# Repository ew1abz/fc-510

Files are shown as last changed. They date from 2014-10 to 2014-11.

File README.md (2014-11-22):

fc-510
======

Frequency Counter FC-510 by wubblick@yahoo.com

[http://radiokot.ru/forum/viewtopic.php?f=10&t=65025](http://radiokot.ru/forum/viewtopic.php?f=10&t=65025)

[www.youtube.com/watch?v=VNKCnef-ynU](www.youtube.com/watch?v=VNKCnef-ynU)

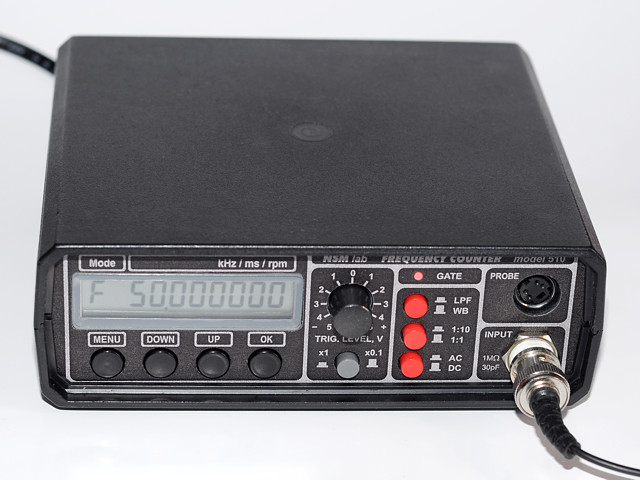
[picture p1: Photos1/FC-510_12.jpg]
requency Counter FC-510 by wubblick@yahoo.com


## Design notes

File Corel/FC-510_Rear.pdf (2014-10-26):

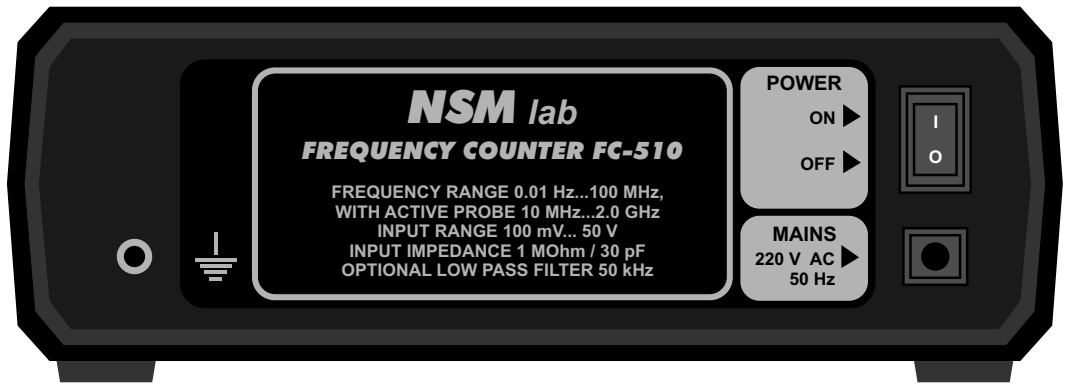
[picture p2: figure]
UEN; TER; NSM; OFF; POWER; MAINS; FREQUENCY RANGE 0.01 Hz...100 MHz, WITH ACTIVE PROBE 10 MHz...2.0 GHz INPUT RANGE 100 mV... 50 V INPUT IMPEDANCE 1 MOhm / 30 pF OPTIONAL LOW PASS FILTER 50 kHz

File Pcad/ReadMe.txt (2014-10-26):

Для просмотра и печати файлов нужна программа PLT_Print.exe
(http://www.platnaya.ru/programs_plt.shtml?from=3050)

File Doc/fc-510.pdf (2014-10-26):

# NSM lab

FC-510

# Частотомер

## руководство пользователя

ver. 1.3

FC-510

### 1. Описание устройства

### 1.1. Технические характеристики

- диапазон измеряемых частот – 0.1 Гц…100 МГц
- измеряемый период – 10 нс…10 с
- измеряемая длительность одиночных импульсов – 100 нс…10 с
- измеряемая частота вращения – 6…999999 об./мин.
- измерение коэффициента заполнения
- вычисление максимальной частоты, минимальной частоты, дрейфа частоты
- режим удержания показаний
- измерительный интервал – 10 мс…10 с
- количество усреднений – 1…100, нелинейная фильтрация
- вычитание промежуточной частоты – ±99.9999 МГц
- диапазон коэффициента деления внешнего прескалера – 1…1000
- встроенный аналоговый интерполятор, разрешение 1 нс
- входное сопротивление – 1 МОм || 30 пФ
- чувствительность – 100 мВ (до 50 МГц)
- максимальное входное напряжение – ±50 В
- регулируемый порог – -0.5…+0.5 В, -5…+5 В
- входной аттенюатор – 1:1, 1:10
- открытый, закрытый вход
- отключаемый ФНЧ 100 кГц
- внешний прескалер до 2 ГГц
- опорный генератор – TCXO, ±2.5 ppm (-20…+70°C), возможность подстройки
- питание – сеть 220 В
- потребляемая мощность – не более 5 Вт
- габариты – 150 x 130 x 50 мм
- вес – 0.4 кг

### 1.2. Назначение устройства

Частотомер FC-510 предназначен для измерения частоты электрических сигналов в диапазоне от 0.1 Гц до 100 МГц (с внешним прескалером – до 2 ГГц). Благодаря использованию метода обратного счета относительная погрешность измерения не зависит от измеряемой частоты и определяется только временем измерения. Использование аналогового интерполятора позволило значительно повысить разрешающую способность. В результате относительная погрешность измерения на интервале 1 с не превышает 4·10⁻⁹ (без учета нестабильности опорного генератора). Кроме измерения частоты возможно измерение периода сигнала, длительности положительных и отрицательных импульсов, коэффициента заполнения (величина, обратная скважности), частоты вращения, а также статистических характеристик сигнала.
Основой частотомера является микросхема CPLD типа EPM3064A фирмы «Altera». В качестве источника опорной частоты применен термокомпенсированный кварцевый генератор на частоту 12.8 МГц с нестабильностью не более ±2.5 ppm в диапазоне температур -20…+70°C. Математическую обработку результатов измерений, а также управление всеми функциями устройства осуществляет микроконтроллер ATmega8 фирмы «Atmel».

### 1.3. Описание устройства

### 1.3.1. Внешний вид устройства

Частотомер собран в пластмассовом корпусе размером 160 x 140 x 60 мм. На передней панели расположены входные разъемы, органы управления и дисплей. На задней панели частотомера находится выключатель питания, сетевой шнур и клемма заземления. Внешний вид передней панели частотомера показан на рис. 1.

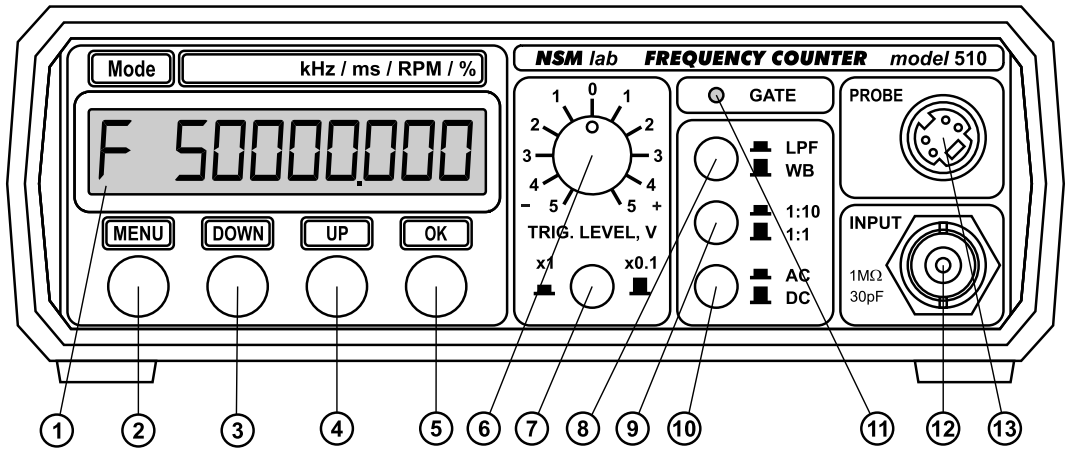
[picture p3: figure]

Рис. 1. Внешний вид передней панели частотомера FC-510.
1 – дисплей; 2 – кнопка входа в меню; 3 – кнопка уменьшения значения;
4 – кнопка увеличения значения; 5 – кнопка подтверждения; 6 – ручка регулировки порога; 7 – кнопка переключения пределов порога; 8 – кнопка включения ФНЧ 100 кГц;
9 – кнопка включения делителя 1:10; 10 – кнопка включения закрытого входа;
11 – светодиод индикации интервала счета; 12 – входной разъем;
13 – разъем для подключения внешнего прескалера.

### 1.3.2. Входные разъемы

Частотомер имеет два входных разъема: разъем BNC для подключения входного сигнала и разъем mini-DIN-4 для подключение внешнего прескалера.
Разъем BNC является основным входом частотомера. Он позволяет измерять частоту до 100 МГц (до 50 МГц сохраняется номинальная чувствительность 100 мВ, на более высоких частотах чувствительность падает). Основной вход имеет стандартные значения входного сопротивления и емкости (1 МОм и 30 пФ). Это делает возможным использование совместно с частотомером стандартных осциллографических щупов, в том числе и с делителем 1:10. Использование делителя позволяет получить высокое входное сопротивление и маленькую емкость. В результате при измерении частоты в схему вносится очень небольшая погрешность, что позволяет, например, контролировать частоту прямо на выводах кварцевого резонатора в генераторах. Однако необходимо помнить, что даже небольшая емкость щупа вызывает некоторое отклонение частоты. Для получения достоверных результатов нужно контролировать частоту на выходе буферного каскада

генератора.
Измерение более высоких частот возможно с использованием внешнего прескалера. Для его подключения предусмотрен специальный разъем. Назначение контактов этого разъема показано на рис. 2.

Рис. 2. Назначение контактов разъема прескалера.

Подключение внешнего прескалера частотомер определяет автоматически по потребляемому току. Когда в цепи +3.3 В (контакт 4 разъема) возникает ток больше 3 мА, прескалер считается подключенным. При этом частотомер начинает учитывать в своих показаниях коэффициент деления прескалера, который можно установить в диапазоне 1…1000 с помощью соответствующего меню.
Выходной сигнал прескалера поступает на контакт 1 разъема. Этот контакт через защитную цепочку подключен к основному входу частотомера. Поэтому при работе с прескалером разъем основного входа частотомера должен быть отключен. При работе с прескалером работают все дополнительные функции, такие как регулировка порога, аттенюатор, фильтр и переключение открытый/закрытый вход. Поэтому для правильной работы прескалера органы управления должны находится в соответствующих положениях, зависящих от типа прескалера.
Контакт 3 разъема предназначен для управления прескалером с помощью однопроводного порта. В модели частотомера FC-510 эта функция не поддерживается.

### 1.3.3. Режимы работы основного входа

Основной вход может быть открытым (DC) и закрытым (AC). Переключение производится кнопкой 10 (рис. 1). При открытом входе постоянная составляющая проходит на вход компаратора частотомера. Это позволяет путем регулировки порога компаратора выделять сигналы, имеющие пьедестал постоянного уровня. При закрытом входе на вход компаратора проходит только переменная составляющая сигнала. В этом случае может быть установлен нулевой порог компаратора, который подойдет для большинства сигналов.
При необходимости измерять сигналы с высоким уровнем, можно кнопкой 9 включить аттенюатор 1:10. При этом эквивалентное значение порога компаратора, приведенное ко входу частотомера, увеличится в 10 раз (до ±50 В).
Для ограничения полосы пропускания частотомер имеет встроенный ФНЧ с частотой среза около 100 кГц. Фильтр включается с помощью кнопки 8. Фильтр необходим при измерении частоты низкочастотных сигналов с малой скоростью нарастания (например, синусоидальных). Применение фильтра увеличивает отношение сигнал/шум и устраняет паразитные срабатывания компаратора на медленных фронтах входного сигнала.

### 1.3.4. Установка порога компаратора

Регулировка порога компаратора производится с помощью переменного резистора 6 (рис. 1). Пределы регулировки переключаются кнопкой 7 и могут быть ±5 В или ±0.5 В. Если
включен | входной | делитель | 1:10, | то эквивалентное | значение | порога,

приведенное ко входу частотомера, увеличится в 10 раз. То же самое происходит и при использовании внешнего щупа с делителем.

### 1.3.5. Индикация интервала счета

На передней панели частотомера имеется светодиод 11 (рис. 1). Он загорается в то время, когда производится счет. Для того, чтобы запустился процесс счета, на вход частотомера должен поступать сигнал, а порог компаратора должен быть правильно настроен. Если компаратор не переключается, то измерение не начинается, и светодиод погашен. Таким образом, светодиод удобно использовать для настройки порога компаратора. Если за установленное время измерения входной сигнал не обнаружен, измерение завершается, индицируется нулевая частота, и измерение запускается снова. Когда входной сигнал обнаруживается, светодиод загорается, и начинается счет. Если в процессе счета входной сигнал исчезает, то производится его ожидание в течение интервала времени, равного времени измерения. Если сигнал не обнаруживается, то измерение завершается и индицируется нулевая частота. Таким образом, максимальное время одного измерения может до двух раз превышать измерительный интервал.

### 1.4. Меню управления

### 1.4.1. Кнопки управления

Для управления частотомером используется система меню. Меню отображается на дисплее. Управление осуществляется с помощью кнопок «MENU», «DOWN», «UP» и «OK». Кнопка «MENU» используется для входа в меню редактирования параметров и для пролистывания списка параметров.
Кнопками «DOWN» и «UP» редактируются значения параметров. Если одну из этих кнопок удерживать, то через 0.8 с начинается автоповтор с периодом 180 мс. После 16 шагов скорость автоповтора возрастает, период становится 60 мс. Еще эти кнопки используются для масштабирования отображаемой на дисплее величины. Одновременное нажатие кнопок «DOWN» и «UP» включает или выключает режим автоматического масштабирования. Кнопка «OK» служит для подтверждения выбранного пункта меню или введенного значения. При ее нажатии происходит возвращение в основное меню. Еще эта кнопка имеет дополнительную функцию включения и выключения режима удержания показаний «HOLD», а также она используется для сброса статистики.

### 1.4.2. Меню заставки

При включении генератора на дисплее появляется меню заставки (рис. 3).

Рис. 3. Меню заставки.

==FC-510==

### 1.4.3. Основное меню

Спустя 2.5 секунды появляется основное меню, где отображается измеренное значение (рис. 4).

Рис. 4. Основное меню.

### 1.4.4. Меню редактирования параметров

Для входа в меню редактирования параметров нужно нажать кнопку «MENU». Этой же кнопкой можно пролистать пункты меню. После пролистывания всего списка параметров происходит выход в основное меню. Выбранный параметр редактируется кнопками «DOWN» и «UP». После редактирования можно перейти к следующему параметру, нажав кнопку «MENU», или вернуться в основное меню нажатием кнопки «OK». При переходе в основное меню осуществляется сохранение значений всех параметров в EEPROM. Список параметров приведен в таблице 1.

Таблица 1. Список редактируемых параметров
Параметр | Минимум | Максимум | Название
Ind | F, P, HI, LO, d, rot, FL, FH, dF | | Режим индикации
G | 10 мс | 10000 мс | Время измерения
A | 1 | 100 | Количество усреднений
IF | -99999.9 кГц | +99999.9 кГц | Промежуточная частота
PrE | 1 | 1000 | Коэффициент деления прескалера
Int | OFF | ON | Включение интерполятора

### 1.4.5. Режим индикации

Режим индикации (режим работы частотомера) можно выбрать в меню «Ind». Режимы пролистываются кнопками «DOWN» и «UP», выбор осуществляется кнопкой «OK» (рис. 5). Возможные режимы работы частотомера приведены в таблице 2.

Таблица 2. Список режимов работы частотомера
Режим | Полное название | Описание
F | Frequency | Измерение частоты
P | Period | Измерение периода
HI | High pulse duration | Измерение длительности импульса высокого уровня
LO | Low pulse duration | Измерение длительности импульса низкого уровня
d | Duty cycle | Измерение коэффициента заполнения
rot | Rotation per minute | Измерение частоты вращения
FH | Frequency high value | Индикация максимальной измеренной частоты
FL | Frequency low value | Индикация минимальной измеренной частоты
dF | Deviation of frequency | Индикация дрейфа частоты

F=50000.000

Рис. 5. Установка режима индикации.

### 1.4.6. Время измерения (Gate)

В меню «G» устанавливается время измерительного интервала (рис. 6). Возможны следующие значения: 10, 20, 50, 100, 200, 500, 1000, 2000, 5000 и 10000 мс. Редактирование значения производится кнопками «DOWN» и «UP». После редактирования можно перейти к следующему параметру, нажав кнопку «MENU», или вернуться в основное меню нажатием кнопки «OK».

Рис. 6. Установка измерительного интервала.

Значение измерительного интервала влияет на точность измерений – чем длиннее измерительный интервал, тем выше точность. С другой стороны, увеличение измерительного интервала ведет к уменьшению частоты обновления измеренного значения на дисплее. Поэтому при оценочных измерениях для комфортной работы может потребоваться уменьшение измерительного интервала.

### 1.4.7. Количество усреднений (Average)

Меню «A» позволяет задать количество усреднений измеряемой величины (рис. 7). Возможно задать количество усреднений от 1 до 100. Редактирование значения производится кнопками «DOWN» и «UP». После редактирования можно перейти к следующему параметру, нажав кнопку «MENU», или вернуться в основное меню нажатием кнопки «OK».

Рис. 7. Установка количества усреднений.

Количество усреднений может быть 1 (усреднение не производится), 2, 5, 10, 20, 50
или 100. Увеличение количества усреднений уменьшает | флуктуации | измеренной

# InD=F==

A=======20

G======200 величины, но в то же время уменьшается скорость реакции на изменение входной частоты. Для ускорения установления усредненного значения используется нелинейный фильтр. Если измеренная частота отклоняется от среднего значения более чем на 6.25%, постоянная времени фильтра уменьшается до нуля. Это существенно сокращает время установления при скачке частоты. С другой стороны, это накладывает ограничение на усреднение результатов измерений при сильно нестабильной частоте.

### 1.4.8. Промежуточная частота (Intermediate Frequency)

В | случае | применения | частотомера | для | измерения | частоты | настройки
супергетеродинных приемников методом измерения частоты гетеродина, имеется возможность вычитания промежуточной частоты. Для ввода значения промежуточной частоты служит меню «IF» (рис. 8). Диапазон задания составляет ±99999.9 кГц. Редактирование значения производится кнопками «DOWN» и «UP». После редактирования можно перейти к следующему параметру, нажав кнопку «MENU», или вернуться в основное меню нажатием кнопки «OK».

Рис. 8. Установка промежуточной частоты.

Значение промежуточной частоты добавляется к измеренному значению частоты. Чтобы вычесть эту частоту, нужно ввести отрицательное значение. Промежуточная частота влияет только на измерение частоты и статистику. Измерение периода, длительности импульсов, коэффициента заполнения и частоты вращения не учитывают значение промежуточной частоты.

### 1.4.9. Коэффициент деления прескалера (Prescaler)

При работе с внешним прескалером частотомер автоматически умножает измеренное значение на коэффициент деления частоты прескалером. Возможно использование прескалеров с коэффициентами деления от 1 (активный пробник без делителя) до 1000. Для задания коэффициента деления прескалера служит меню «PrE» (рис. 9). Редактирование значения производится кнопками «DOWN» и «UP». После редактирования можно перейти к следующему параметру, нажав кнопку «MENU», или вернуться в основное меню нажатием кнопки «OK».

Рис. 9. Установка коэффициента деления прескалера.

# Pre====128

IF=455.0000

Введенный коэффициент деления прескалера вступает в силу только тогда, когда обнаруживается подключение внешнего прескалера. Коэффициент влияет на результаты всех измерений, кроме измерения коэффициента заполнения.

### 1.4.10. Включение интерполятора (Interpolator)

Частотомер имеет встроенный аналоговый интерполятор, который позволяет увеличить разрешающую способность измерения интервалов времени и таким образом повысить точность измерений. Данная модель частотомера имеет всего один интерполятор, поэтому при измерении длительности импульсов и коэффициента заполнения интерполятор не используется. Интерполятор можно включить или выключить с помощью меню «Int» (рис. 10). Включение осуществляется с помощью кнопки «UP», а выключение – с помощью кнопки «DOWN».

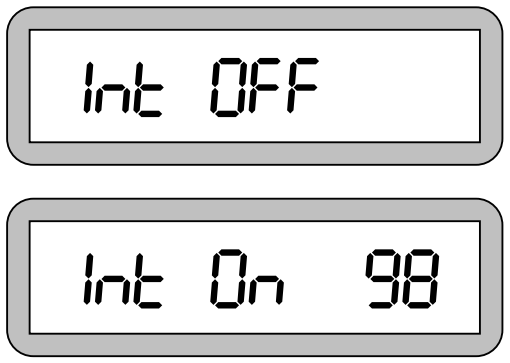
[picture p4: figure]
Int=On==98; Int=OFF==

Рис. 10. Выключение и включение интерполятора.

Когда интерполятор выключен, отображается надпись «OFF». Если же интерполятор включен, то отображается надпись «On» и значение, полученное при калибровке интерполятора. Это значение представляет собой количество отсчетов интерполятора на один период опорной частоты. Значение должно лежать в пределах 70…110. Выход значения за эти пределы говорит о неисправности схемы интерполятора.

### 1.5. Режимы работы частотомера

### 1.5.1. Режим измерения частоты (Frequency)

В режиме измерения частоты на индикаторе отображается значение измеренной частоты в кГц (рис. 11). Относительная погрешность измерения частоты зависит от длительности измерительного интервала (см. меню «G») и от того, используется ли аналоговый интерполятор (см. меню «Int»).
Если измерение проводится с помощью внешнего прескалера, то частотомер автоматически обнаруживает его подключение и умножает измеряемую частоту на коэффициент, заданный в меню «PrE».

Рис. 11. Индикация значения частоты 455 кГц.

Если в меню «IF» задано ненулевое значение промежуточной частоты, то к измеренному значению будет добавляться значение промежуточной частоты. Если реальная частота выше на величину промежуточной частоты, следует вводить положительное значение промежуточной частоты, если ниже – отрицательное. Когда выводится значение с учетом промежуточной частоты, то после символа «F» отображается точка (рис. 12).

Рис. 12. Индикация значения 13 МГц с учетом промежуточной частоты.

### 1.5.2. Режим измерения периода (Period)

В режиме измерения периода фактически производится измерение частоты, но отображается обратная величина 1/f (рис. 13). При нулевом значении частоты вместо периода отображается ноль. Все дополнительные режимы, действующие для измерения частоты, кроме учета промежуточной частоты, действуют и при измерении периода.

Рис. 13. Индикация значения периода 2.5 мкс.

### 1.5.3. Режим измерения длительности импульсов ВЫСОКОГО уровня (High level)

В этом режиме производится измерение суммарной длительности импульсов ВЫСОКОГО уровня за время измерительного интервала. Полученное значение делится на количество зарегистрированных импульсов, в результате получается длительность одного импульса (рис. 14). Интерполятор в этом измерении не участвует. Возможно измерение длительности даже одиночных импульсов.

F.=13000.000

P=0.0025000

F=455.00000

Рис. 14. Индикация длительности импульса 333 мкс.

### 1.5.4. Режим измерения длительности импульсов НИЗКОГО уровня (Low level)

В этом режиме производится измерение суммарной длительности импульсов НИЗКОГО уровня за время измерительного интервала. Полученное значение делится на количество зарегистрированных импульсов, в результате получается длительность одного импульса (рис. 15). Интерполятор в этом измерении не участвует. Возможно измерение длительности даже одиночных импульсов.

Рис. 15. Индикация длительности импульса 322 мкс.

### 1.5.5. Режим измерения коэффициента заполнения (Duty cycle)

При измерении коэффициента заполнения (рис. 16) сначала измеряется длительность ВЫСОКОГО уровня, затем длительность НИЗКОГО уровня, затем вычисляется значение d = HI / (HI + LO). Интерполятор в измерении не участвует.

Рис. 16. Индикация коэффициента заполнения 0.999.

### 1.5.6. Режим измерения частоты вращения (Rotations per minute, rpm)

При измерении частоты вращения производится обычное измерение частоты, только результат переводится в единицы оборотов в минуту (рис. 17). Все дополнительные режимы, действующие для измерения частоты, кроме учета промежуточной частоты, действуют и при измерении частоты вращения.

D=====0.999

LO=0.322000

HI=0.333000

Рис. 17. Индикация частоты вращения 3499.99 об./мин.

### 1.5.7. Вычисление максимальной частоты (Frequency High)

Для сигналов, частота которых не остается постоянной, а меняется в некоторых пределах, есть возможность вычисления максимальной частоты. В этом режиме непрерывно производятся измерения частоты с заданным измерительным интервалом. Индицируется максимальный измеренный результат (рис. 18). Для сброса результата нужно нажать кнопку «OK», при этом измерение останавливается, а показания начинают мигать. Вторичное нажатие кнопки «OK» сбрасывает значение максимальной частоты и возобновляет измерения. При этом показания сменяются значением текущей частоты, и снова начинает накапливаться статистика.

Рис. 18. Индикация максимальной частоты 455.9 кГц.

### 1.5.8. Вычисление минимальной частоты (Frequency Low)

Имеется также возможность вычисления минимальной частоты. В этом режиме непрерывно производятся измерения частоты с заданным измерительным интервалом. Индицируется минимальный измеренный результат (рис. 19). Для сброса результата нужно нажать кнопку «OK», при этом измерение останавливается, а показания начинают мигать. Вторичное нажатие кнопки «OK» сбрасывает значение минимальной частоты и возобновляет измерения. При этом показания сменяются значением текущей частоты, и снова начинает накапливаться статистика.

Рис. 19. Индикация максимальной частоты 454.3 кГц.

### 1.5.9. Вычисление отклонения частоты (Deviation of Frequency)

В этом режиме непрерывно производятся измерения частоты с заданным измерительным интервалом. Индицируется разность между текущим значением и первым измеренным значением (рис. 20). Для сброса результата нужно нажать кнопку «OK», при

FL=454.3000

FH=455.9000

# rot=3499.99

этом измерение останавливается, а показания начинают мигать. Вторичное нажатие кнопки «OK» сбрасывает значение дрейфа частоты и возобновляет измерения. При этом показания сменяются значением текущей частоты, и снова начинает накапливаться статистика.

Рис. 20. Индикация дрейфа частоты -0.85633 кГц.

### 1.6. Дополнительные функции частотомера

### 1.6.1. Удержание показаний (Hold)

Для временной приостановки измерений с индикацией последнего измеренного значения служит режим удержания показаний. Включается он нажатием кнопки «OK». В режиме удержания показаний значение на дисплее мигает. Выйти из режима удержания показаний можно вторичным нажатием кнопки «OK».

### 1.6.2. Масштабирование показаний (Scale)

Положение децимальной точки можно менять (рис. 21) с помощью кнопок «DOWN» (точка перемещается влево) и «UP» (точка перемещается вправо).

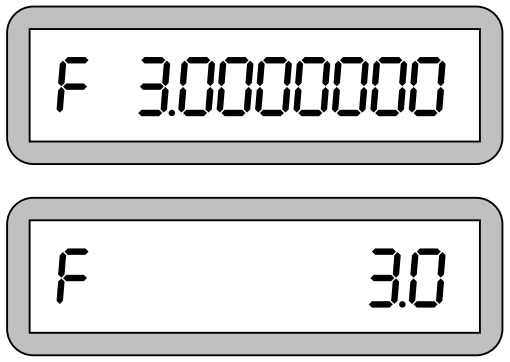
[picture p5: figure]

Рис. 21. Два разных способа индикации частоты 3 кГц.

Если измеренная величина не умещается в разрядную сетку с текущим положением точки, возникает переполнение, которое индицируется в виде черточек (рис. 22). В этом случае необходимо запятую сдвинуть вправо с помощью кнопки «UP».

DF=-0.85633

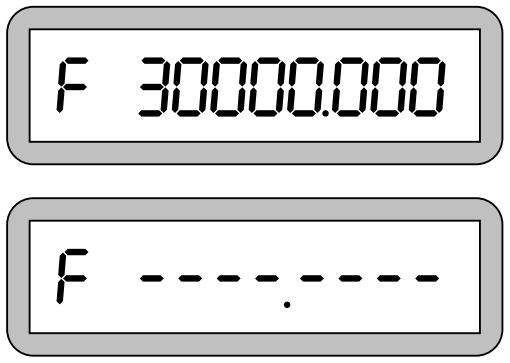
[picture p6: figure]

Рис. 22. Переполнение при индикации частоты 30 MГц.

### 1.6.3. Автоматическое масштабирование показаний (Auto scale)

Имеется режим автоматического масштабирования показаний, когда положение запятой определяется измеренным значением. Для включения этого режима нужно одновременно нажать кнопки «DOWN» и «UP». При этом на дисплее появляется соответствующая надпись (рис. 23), которая исчезает через 2 сек.

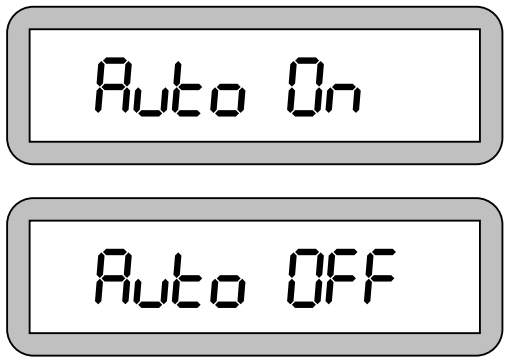
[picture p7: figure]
=Auto=OFF=; =Auto=On=

Рис. 23. Индикация режима автоматического масштабирования.

В каждом цикле измерения запятая может сдвигаться только на одну позицию (рис. 24). Поэтому для нормализации вывода может потребоваться несколько циклов измерения (до шести).

F=-.-------

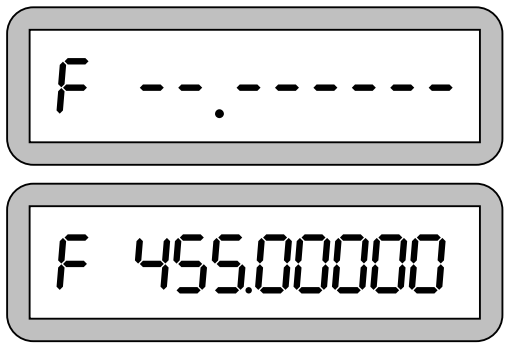
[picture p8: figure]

Рис. 24. Действие автоматического масштабирования.

### 1.6.4. Калибровка частотомера (Calibration)

Калибровка частотомера производится по эталонному генератору или частотомеру. Перед калибровкой необходимо прогреть прибор в течение 30 мин. К генератору импульсов необходимо вместе с частотомером подключить эталонный прибор. Регулировкой порога компаратора нужно добиться устойчивых показаний. Калибровку желательно проводить при длительности измерительного интервала (Gate) не меньше 1 с, рекомендуется – 10 с. Вращая подстроечный элемент опорного генератора, нужно добиться совпадения показаний частотомера с эталонным.

### 2. Информация о разработчике

### 2.1. Разработчик

NSM lab
e-mail: wubblick@yahoo.com

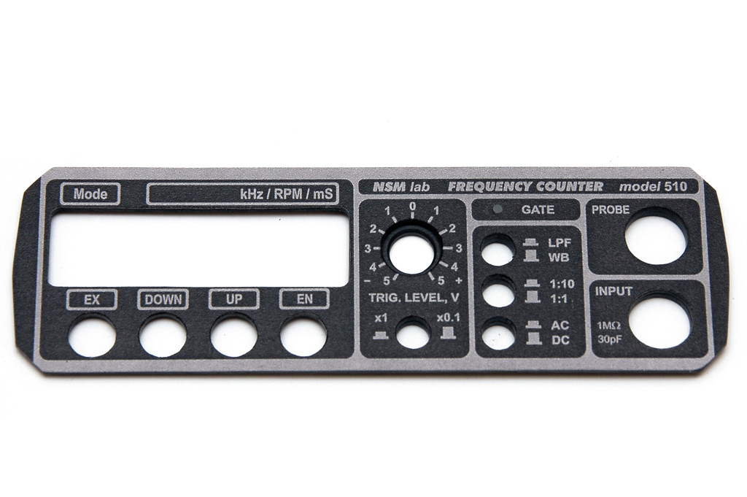
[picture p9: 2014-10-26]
Photos3/FC-510_front_panel1.jpg

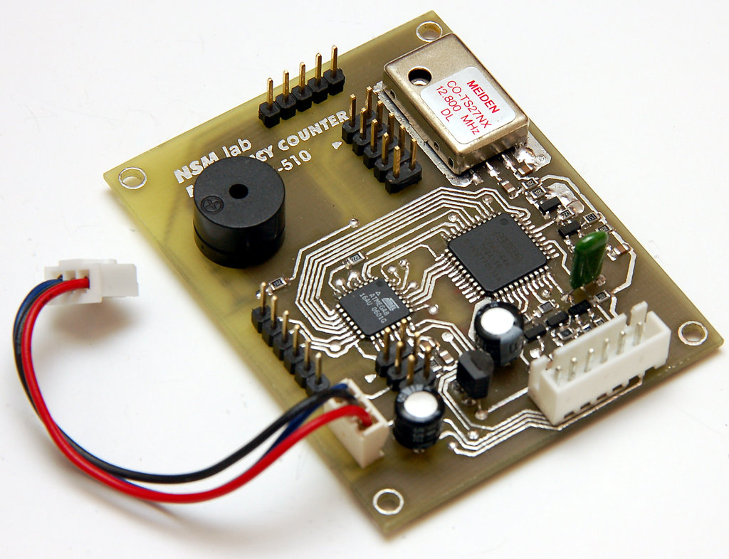
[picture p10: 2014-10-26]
Photos1/FC-510_main_board.jpg

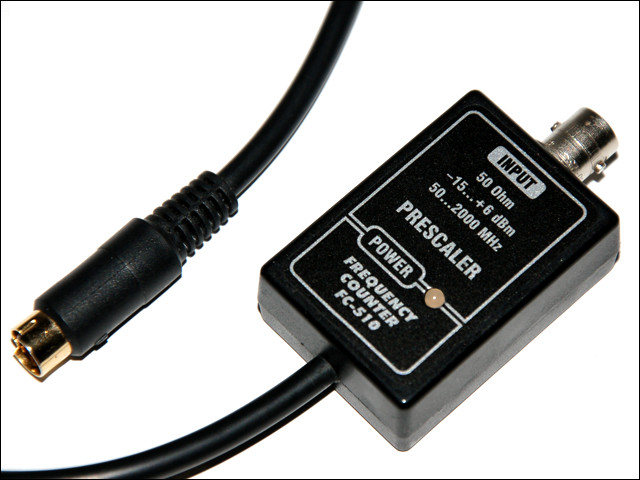
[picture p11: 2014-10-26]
Photos1/FC-510_prescaler.jpg

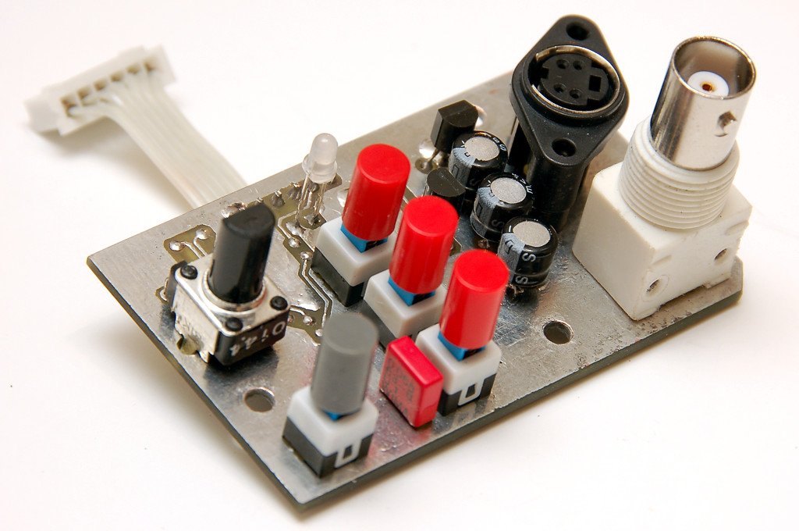
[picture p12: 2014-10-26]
Photos2/FC-510_front_board1.jpg

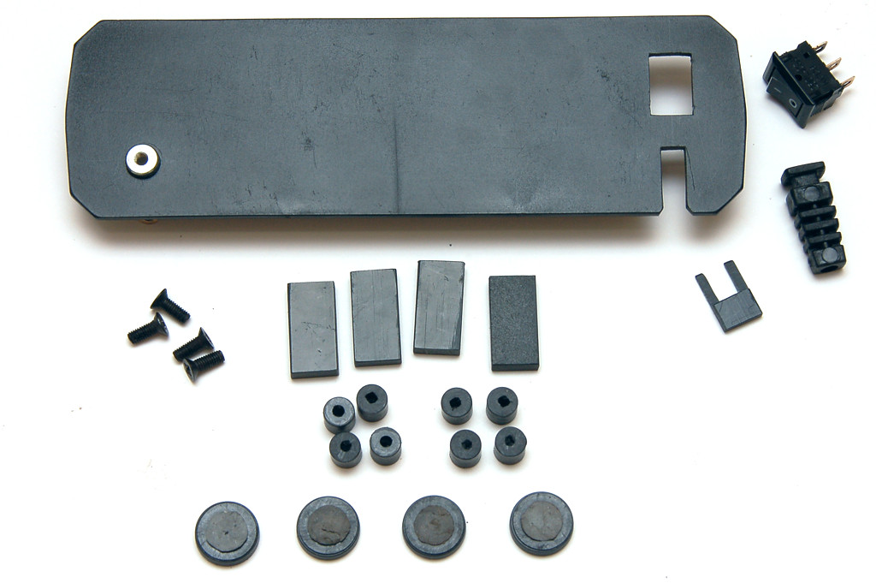
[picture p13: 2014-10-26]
Photos2/FC-510_panel_rear_det.jpg

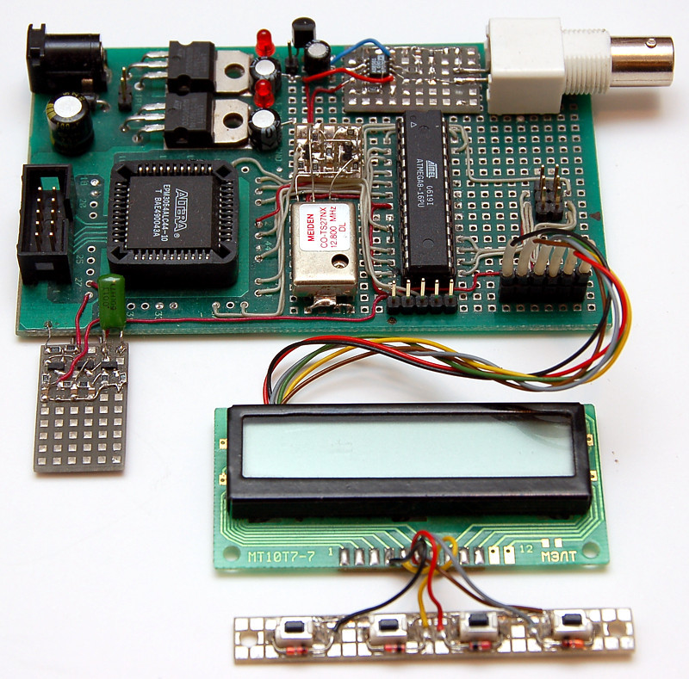
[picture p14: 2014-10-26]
Photos1/FC-510_proto.jpg

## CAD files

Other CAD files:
AutoCAD/FC-510_det.dwg
AutoCAD/FC-510_comp.dwg

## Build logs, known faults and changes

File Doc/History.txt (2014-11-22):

FC-510 history:

Видео: http://www.youtube.com/watch?v=VNKCnef-ynU

Version 0.7

Fref = 12.8 МГц
10-битный счетчик интерполятора

Version 0.8

Fref = 100 МГц (PLL)
8-битный счетчик интерполятора

? Выбор Fref. При Fref = 100 MHz интерполятор
  работает не очень хорошо, показывает значения,
  по модулю меньше нужных. Непонятно, какой вклад
  вносит джиттер измеряемого сигнала.
  На практике той точности, которую обеспечивает
  Fref = 12.8 MHz, вполне достаточно.
  Применение PLL с VCO 100 MHz - это усложнение схемы,
  добавление джиттера (как минимум, в роли VCO должен
  быть VCXO), схема с трудом умещается в EPM3064
  (разные режимы работы не влезут).
+ Fref = 12.8 МГц

? Согласование выхода TCXO со входами.
  Похоже, TCXO имеет на выходе разделительный
  конденсатор. Прямое тактирование CPLD не
  получается. Тактирование CPU тоже не очень:
  процессор работает (режим генератора - HF XTAL
  Full Amplitude), но с XTAL2 плохо тактируется
  CPLD.
+ На выходе TCXO установить буферный усилитель
  ОЭ-ОБ на BFT93. Это универсальное решение, будет
  работать со всеми генераторами. С выхода усилителя
  сигнал на CPLD. В CPLD предусмотреть выход
  тактовой частоты Fcpu = Fref/1, Fref/2, Fref/4,
  Fref/8. Это позволит использовать любой TCXO
  вплоть до 100 MHz.

? Нужно ли пропускать PulseIn интерполятора
  через дополнительный LCELL?
- Никакого эффекта не замечено. Возможно,
  чуть-чуть лучше, но на грани заметности.

? Уменьнение шума калибровочного коэффициента.
+ Сделал функцию, которая позволяет проводить
  калибровку N раз. Поставил N = 10,
  калибровочный коэффициент сейчас гораздо
  стабильнее.

? Делать ли второй интерполятор для измерения
  интервалов?
- Нет. Не в этой модели.
  Интервалы измерять без интерполяции,
  хотя при больших длительностях интерполятор
  можно использовать.

- Плохо работает буфер (низкий коэффициент передачи,
  при этом появляется смещение, зависящее от формы
  входного сигнала).
+ Исправил заменой JFET. Для норальной работы буфера
  нужен транзистор с начальным током стока
  5 - 10 мА и напряжением отсечки 2 - 4 В.
  Напряжение на выходе OP777 должно быть -0.5..-2 В.

- Повышенный уровень помех на выходе буфера.
+ Это помехи ключевого стабилизатора источника
  питания. Из-за неудачной точки заземления
  инвертора (удвоителя) напряжения помехи по
  земле проникали на уровень -5 В. Транзистор,
  регулирующий ток JFET, можно представить
  как каскад с ОБ, усиливающий пульсации на
  шине -5 В и передающий их на выход.
  Изменил точку заземления удвоителя.
  Добавил LC фильтр (56 uH + 4.7 uF x 25 V) перед 79L05.
  Увеличил дроссель LM2576 до 470 uH (был 100 uH).
- Применить в источнике питания LM2596 и побольше
  дросселя на выходе.
  На входе основной платы добавить электролиты +
  керамика.
+ Или применить линейный источник питания, что лучше
  всего, потребление ведь незначительное.
+ Потребление по +5 В составляет 110 мА (90 мА без
  входной платы), по -5 В - 18 мА.

- Ложные срабатывания компаратора на медленно
  меняющемся сигнале.
+ Увеличил гистерезис до 85 мВ (резистор ПОС 56 К).
  Добавил резистор 120 К для симметрирования гистерезиса.

? Почему-то для импульсного сигнала порог чувствительности
  100 мВ, а по теории должен быть 170 мВ.
  Выбросы на фронтах?

- Защитный диод с малыми утечками BAV199,
  маркировка JY* (p, t)
  Не смог найти, пока установил BAV99.

- Поменять обозначения M и N в документации согласно документу
  Agilent.

- Сделать вариант статической индикации на 74HC595 + LED.

Version 1.0

  Работала у меня 5 лет в частотомере с прошивкой Ver10.
  Только измерение частоты, есть делитель Fcpu.

Version1.1

+ Altera: убрал делитель тактовой частоты для CPU.

+ Altera: на выход SData вывожу не FrefGate, а FinGate.

+ Altera: задействовал сигналы Mode. Теперь выход FinGate поступает
  на d-вход FrefGate через мультиплексор. В зависимости от значения
  Mode по логике "И" добавляется либо Fin, либо !Fin. Это позволяет
  с помощью счетчика FrefCnt считать длительность только единиц
  или только нулей в серии входных импульсов. Таким образом можно
  сделать измерение th и tl.

- Измерение длительности импульсов.
+ Реализовал заполнением Fref по серии импульсов внутри Gate.
  Заполняется суммарная длительность единиц (нулей),
  результат делится на кол-во импульсов.
? Что удивительно, нормально измеряются импульсы от 10 нс.

- Предусмотреть режим измерения дрейфа (отклонения) частоты.
+ Реализовал режим dF.

- Auto Range.
+ Реализовал.

- Ограничение количества значащих цифр в зависимости от времени
  измерения?
? Зачем?

- Счет событий MODE_N сделать на таймере микроконтроллера.
  Для этого в Altera на выход QFin включать непосредственно
  сигнал Fin. Обновление дисплея делать в процессе счета
  по таймеру. Счет будет возможен до 6.4 МГц.
- Пока не делал за ненужностью.

- Счет времени в воротах MODE_GC можно реализовать так: ворота
  делаются в Altera, на выход QRef во время ворот поступает
  частота, например, 10 мкс (Fclk/128). Счет времени делать таймером
  микроконтроллера. Обновление дисплея делать в процессе счета.
- Пока не делал за ненужностью.

- Режимы прямого и обратного таймеров реализовать только на
  микроконтроллере.
? Необходимость обратного таймера под вопросом.
  Как ему задавать начальное значение?
- Пока не делал за ненужностью.

Version1.2

+ Изменил алгоритм масштабирования показаний. Теперь частота
  вычисляется для всех режимов и хранится в единицах 100 мкГц.
  Это позволило корректно выводить статистику.

- Задать PAR_PRE_NOM таким, как у внешнего делителя (когда
  будет известно).

? Нужен ли порт на PC?
- Да. Хотя бы в простейшем варианте,
  типа "F 50,000.000 kHz" <Cr><Lf> 

? Защиту на прескалер диоды?
  На входе BF960, BF998 для получения 1 МОм.

- Предусмотреть подключение LCD 1601

Version1.3

+ Минус теперь вывожу перед числом, а не вместо самой левой
  цифры числа.

+ Добавил ограничение для отрицательных чисел.

+ Исправил масштабирование для отрицательных чисел.

+ Добавил по кнопке "MENU" выход из HOLD
  без сброса статистики.

Version1.4

+ Добавлены две конфигурации для компиляции:
  LCD10 (дисплей MT-10T7 или MT-10T8) и
  LCD16 (дисплей 1601).
? Адресация символов 1 строка 16 или 2 строки по 8?
  Пока отлажено на дисплее 1602.

+ В варианте LCD16 добавлена поддержка последовательного
  порта. В порт передается копия дисплея в ASCII.

? Наблюдается погрешность при измерении периода и длительности
  импульсов на временах порядка сотен мс. Дело в том, что
  частота внутри представлена в сотнях микрогерц (при измерении
  периода и длительности расчет ведется тоже через эквивалентную
  частоту).
+ Внес изменения в модуль Count.c. В режимах MODE_HI, MODE_LO и
  MODE_P вычисляется не частота, а сразу период, который
  сохраняется в той же переменной Freq. В режимах
  MODE_HI и MODE_LO интерполятор не используется.

- Перенести работу с UART в отдельный модуль, чтобы порт
  работал с любым индикатором.

- Сделать внешний прескалер с входом 50 Ом на LMX2322 + ATtiny13.
+ Сделал.

+ Настройка частотомера:
  В первую очередь нужно измерить напряжение на выходе ОУ U1,
  когда на входе нет никакого сигнала. Оно должно быть около
  -0.5..-2 В. Если напряжение сильно отличается, требуется
  замена полевого транзистора VT1. Подойдут экземпляры с
  начальным током стока  5 - 10 мА и напряжением отсечки 2 - 4 В.

  Подстроечные конденсаторы на входной плате служат для компенсации
  делителей и подстройки входной емкости прибора. Вообще,
  равномерность АЧХ для входного усилителя частотомера не является
  такой важной, как для осциллографа. Поэтому эти подстройки можно
  просто опустить. Но если есть желание, можно и подстроить. На вход
  нужно подать прямоугольные импульсы частотой, например, 1 кГц.
  Сигнал нужно контролировать осциллографом на эмиттере VT3.
  Сначала включить делитель 1:1. Подстроечным конденсатором C2
  добиться отсутствия выброса на фронте импульса.
  Если интересует точная входная емкость (это важно при использовании
  внешних щупов), то сигнал на вход подают через щуп со встроенным
  делителем 1:10 и подстройкой C6 добиваются отсутствия выброса.
  После регулировки C6 обычно требуется пропорциональная подстройка
  C2, поэтому нужно будет сделать несколько приближений.
  Затем на вход частотомера нужно подать сигнал непосредственно,
  включить делитель 1:10 и емкостью C4 добиться отсутствия выброса.

  Не помешает проверить шкалу интерполятора. Для этого нужно
  зайти в меню Int, интерполятор должен быть включен, показания
  должны быть 100±10. Если отклонение больше, то резистором R13
  на основной плате нужно их подкорректировать.

  Но самая главная регулировка частотомера - установка опорной
  частоты. На вход нужно подать сигнал образцовой частоты (например,
  сигнал 1PPS с приемника GPS или 5 - 10 МГц с термостатированного
  генератора) и подстроечным конденсатором генератора выставить
  номинальное значение показаний.

+ 16.08.2013 Исправил ошибку для индикатора 1602(01) при индикации
  частоты с учетом IF. Вместо "F с точкой" вывожу "f".

10.09.2013

+ Исправил формулу расчета частоты с учетом IF

+ Исправил округление отрицательных значений частоты

+ Добавил в 10 раз более быстрый автоповтор после 100 повторов
! При быстром автоповторе строка не успевает передаваться в порт.
  В принципе, не очень это и нужно, но некрасиво. Запретить
  передачу при быстром автоповторе? Или прореживать?

+ Увеличил шаг изменения IF до 1 кГц после ±1000.0 кГц

+ Добавил сброс параметров Gate, Average, IF, Prescaler на
  номинальные значения (1000, 1, 0 и 1 соответственно) при
  нажатии UP + DOWN.

13.11.2014 - Version1.7

+ Добавил три конфигурации компиляции: LCD10, LCD1601, LCD1602.
  Разделил модули работы с дисплеем на следующие части:
  Disp.c, Disp.h - общие функции работы с дисплеем. Здесь всегда
  формируется полная строка (как для LCD16XX). На дисплей LCD16XX
  она передается без каких-либо преобразований, а на дисплей
  LCD10 передается только название параметра и числовое значение,
  точки вместо отдельных знакомест добавляются к символам.
  Lcd16xx, Lcd.h - модуль поддержки дисплеев LCD16XX.
  Lcd10, Lcd.h - модуль поддержки дисплея LCD10.
  Заголовочный файл у них общий Lcd.h, интерфейс дисплеев сделан
  одинаковым.

+ Выделил работу с портом в отдельный модуль. Теперь порт доступен
  и в конфигурации с дисплеем LCD10. В порт отправляется полная
  строка (как для LCD16XX).

+ При передаче данных в порт добавлена проверка, закончилась ли
  предыдущая передача. Иначе при быстром автоповторе передавалась
  искаженная строка.

+ Добавил новый режим индикации FIF. Теперь для включения учета
  ПЧ нужно вместо F выбрать FIF. Для отключения учета ПЧ не требуется
  сбрасывать ее значение в 0, достаточно перейти к режиму индикации F.

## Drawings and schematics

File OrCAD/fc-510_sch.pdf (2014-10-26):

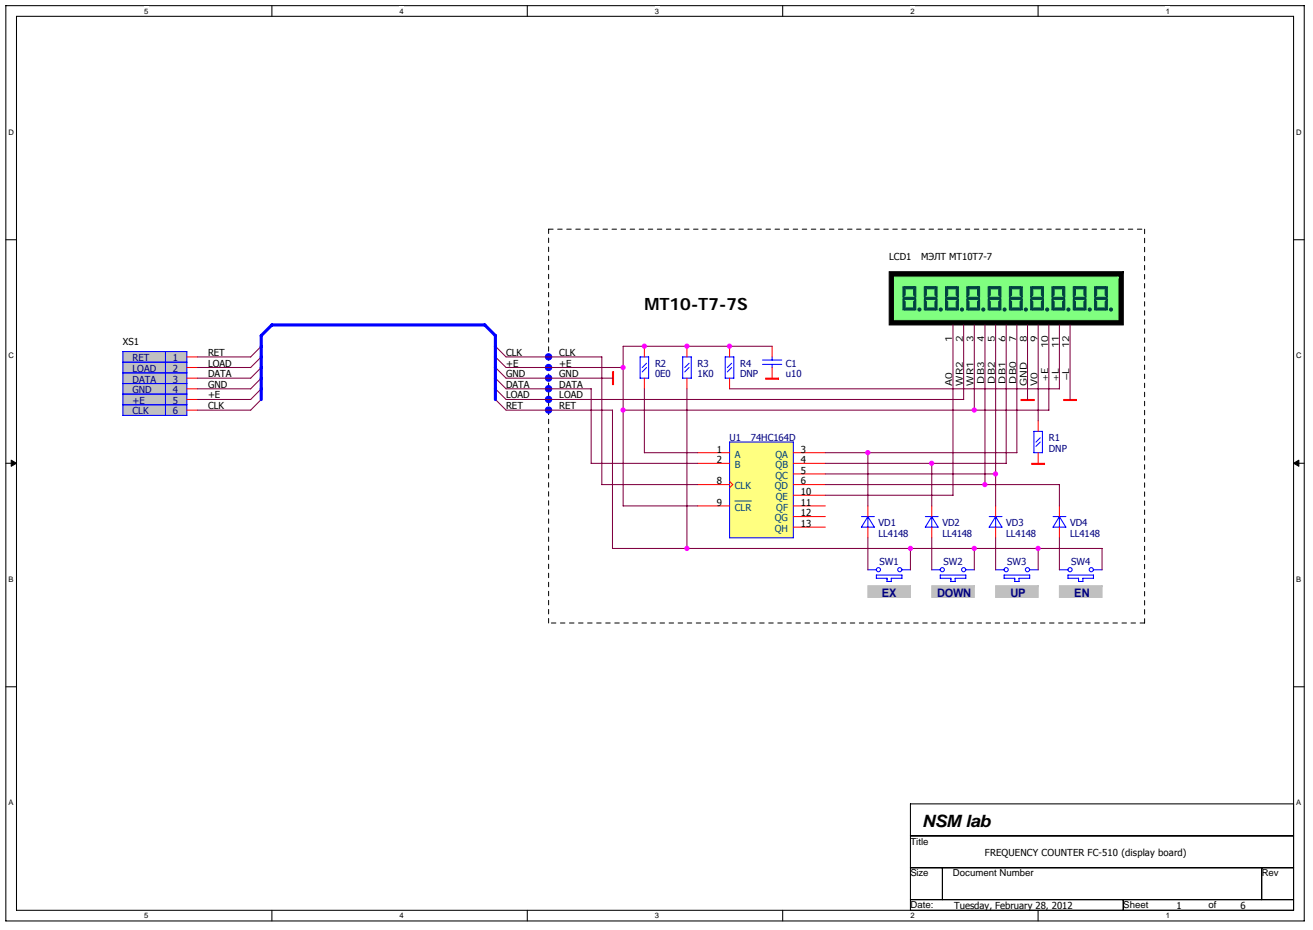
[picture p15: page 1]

RET | 1
LOAD | 2
DATA | 3
GND | 4
+E | 5
CLK | 6

U1 74HC164D
A QA B QB

R1 DNP

B | | | | | 8 9 | QC CLK QD QE CLR QF QG QH | 5 | B

10 | | LL4148 | | VD3 LL4148

NSM lab

Title FREQUENCY COUNTER FC-510 (display board)

Size | Document Number | | Rev

Date: Tuesday, February 28, 2012 | | Sheet 1 of 6

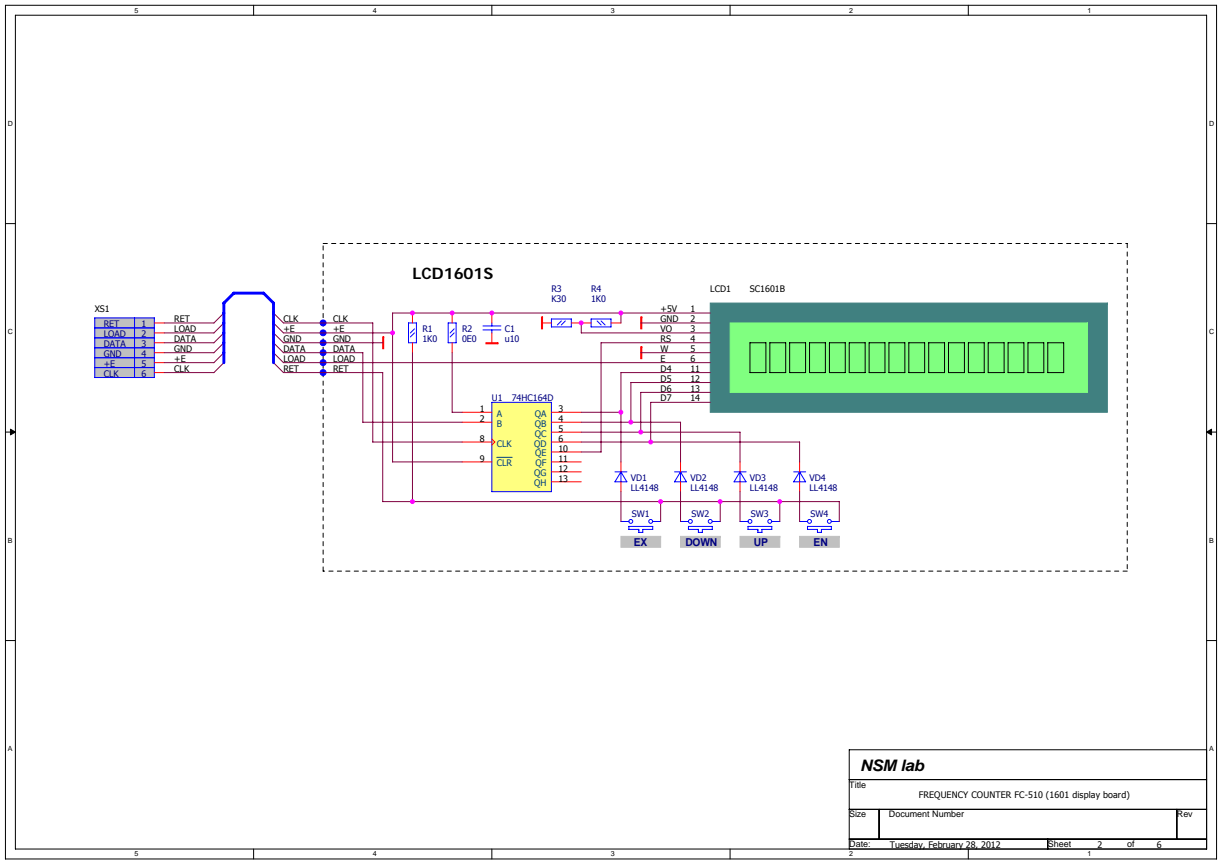
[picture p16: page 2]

RET | 1
LOAD | 2
DATA | 3
GND | 4
+E | 5
CLK | 6

10 | VD1 LL4148 | VD2 LL4148 | VD3 LL4148

B | | | | 8 9 | CLK QD QE CLR QF QG QH | 6 | B

NSM lab

Title FREQUENCY COUNTER FC-510 (1601 display board)

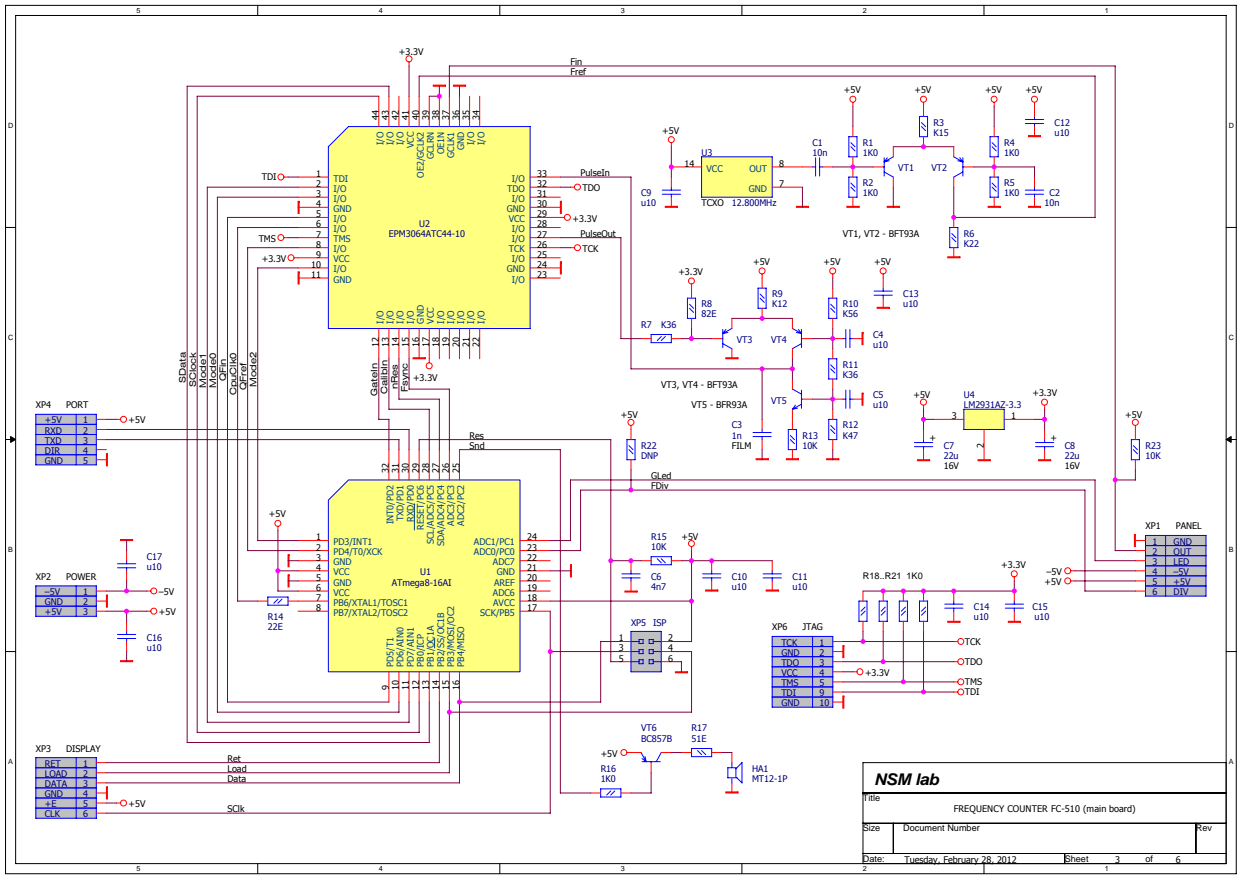
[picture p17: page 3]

+3.3V | Fin

Fref

+5V | 1
RXD | 2
TXD | 3
DIR | 4

B | | | | 7 PB6/XTAL1/TOSC1 8 PB7/XTAL2/TOSC2 R14 22E | Snd | R22 GLed | 16V | 16V | XP1 PANEL | B

FDiv

1 | GND
2 | OUT
3 | LED
4 | –5V
5 | +5V

GND | 2
+5V | 3

XP5 ISP

TCK | 1
TDO | 3
VCC | 4
TMS | 5
TDI | 9
GND | 10

TCK

XP3 DISPLAY | | 6 | R17 51E

RET | 1
LOAD | 2
DATA | 3
GND | 4
+E | 5
CLK | 6

Title FREQUENCY COUNTER FC-510 (main board)

+5V SClk

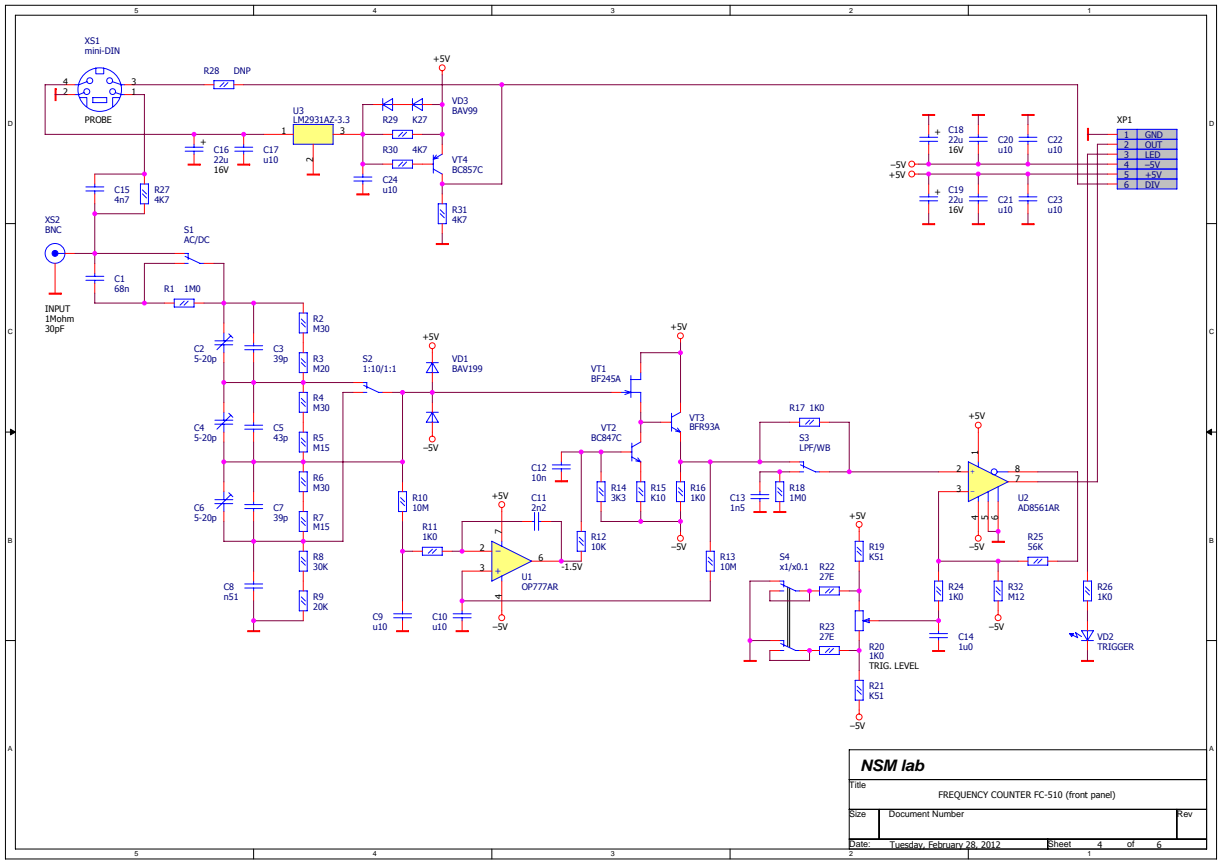
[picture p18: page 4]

1 | GND
2 | OUT
3 | LED
4 | –5V
5 | +5V
6 | DIV

NSM lab

Title FREQUENCY COUNTER FC-510 (front panel)

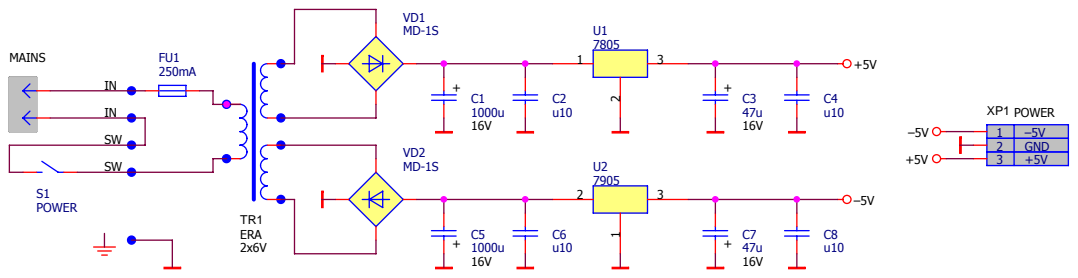
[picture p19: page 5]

IN
SW

1 | –5V
2 | GND
3 | +5V

NSM lab

Title FREQUENCY COUNTER FC-510 (power supplay board)

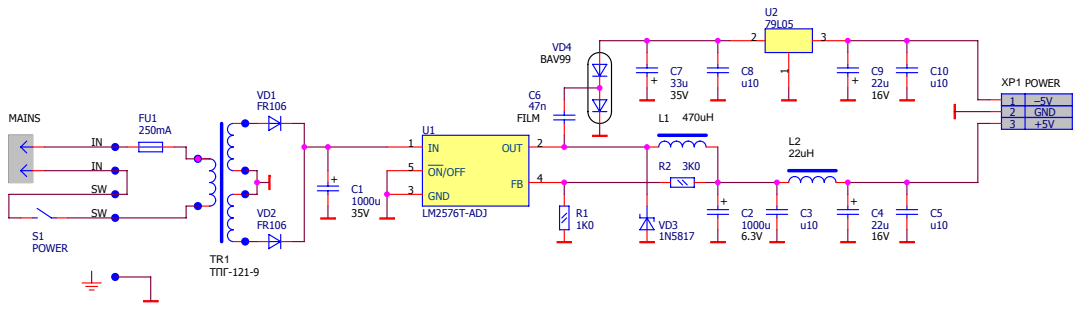
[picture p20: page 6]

NSM lab

Title FREQUENCY COUNTER FC-510 (power supplay board)

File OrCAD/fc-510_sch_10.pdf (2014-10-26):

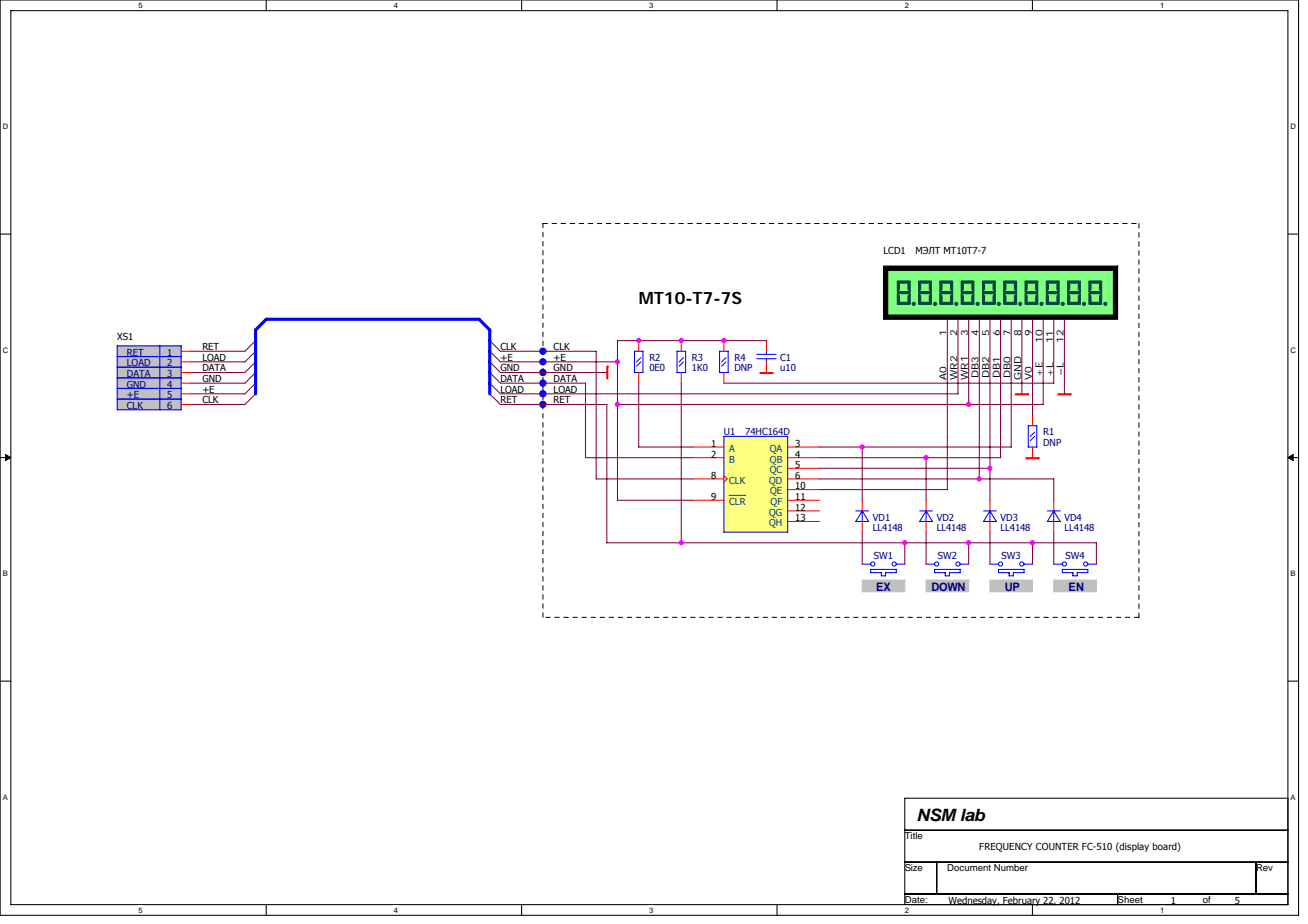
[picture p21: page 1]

RET | 1
LOAD | 2
DATA | 3
GND | 4
+E | 5
CLK | 6

10 | | LL4148 | VD3 LL4148

FREQUENCY COUNTER FC-510 (display board)

Size | Document Number | Rev

Date: Wednesday, February 22, 2012 | Sheet of 1 5

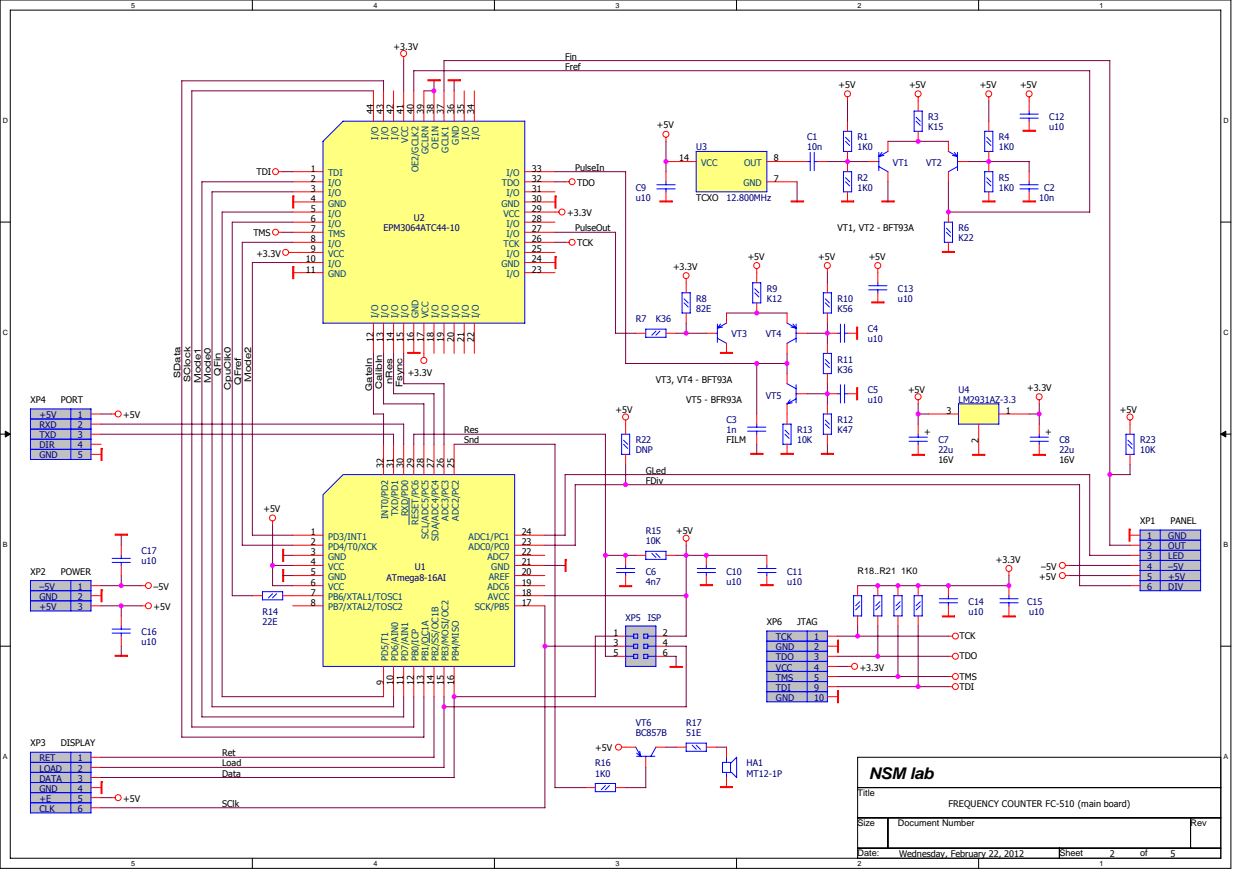
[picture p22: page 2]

+5V | 1
RXD | 2
TXD | 3
DIR | 4
GND | 5

FDiv

1 | GND
2 | OUT
3 | LED
4 | –5V
5 | +5V

GND | 2
+5V | 3

TCK | 1
TDO | 3
VCC | 4
TMS | 5
TDI | 9
GND | 10

RET | 1
LOAD | 2
DATA | 3
GND | 4
+E | 5
CLK | 6

FREQUENCY COUNTER FC-510 (main board)

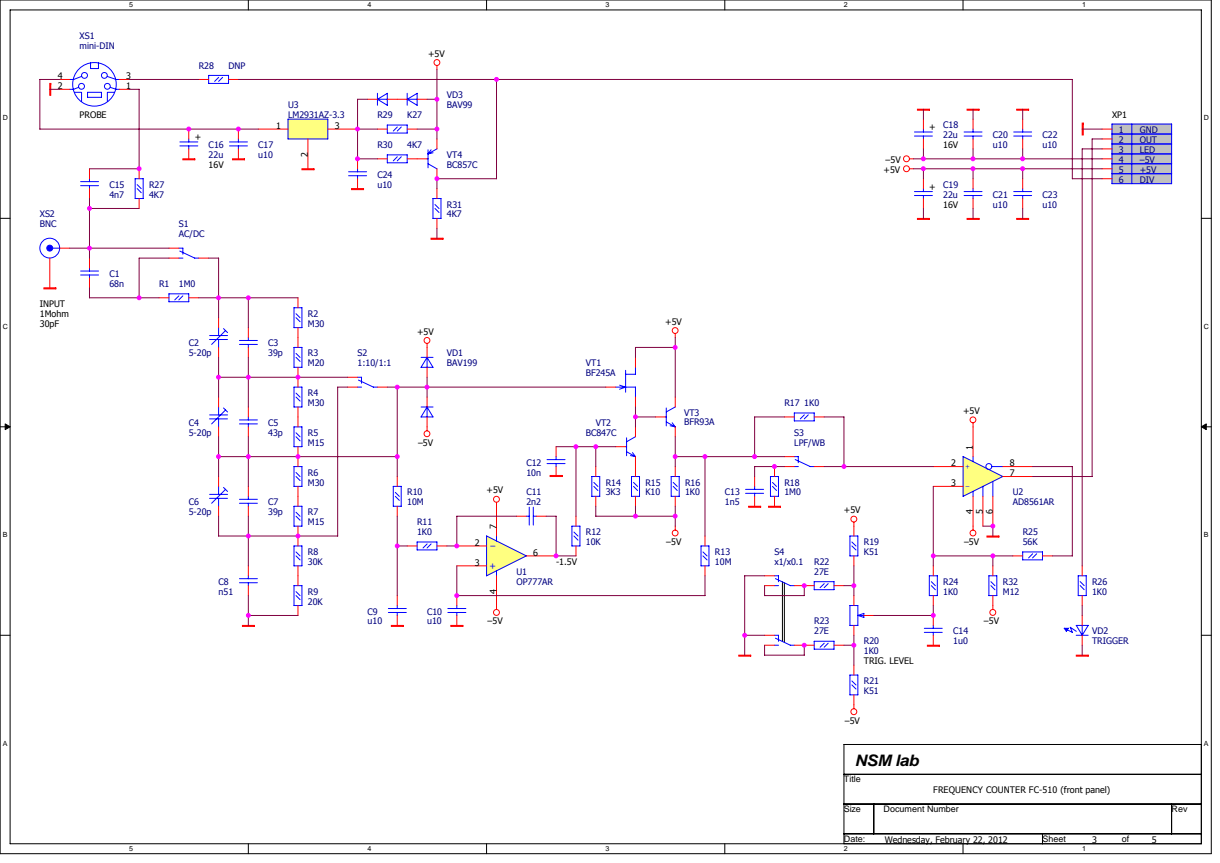
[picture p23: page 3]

1 | GND
2 | OUT
3 | LED
4 | –5V
5 | +5V
6 | DIV

FREQUENCY COUNTER FC-510 (front panel)

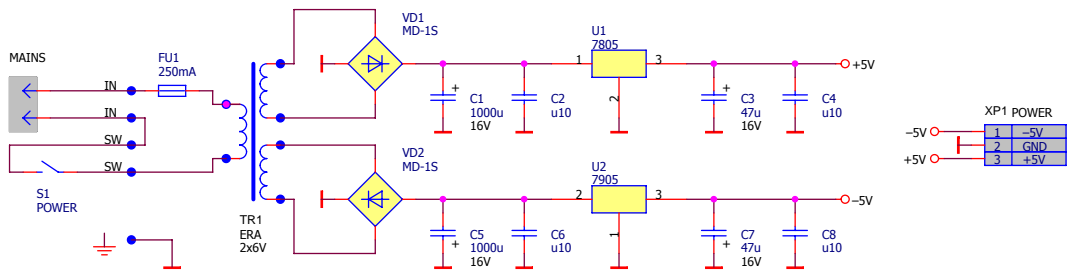
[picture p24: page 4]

1 | –5V
2 | GND
3 | +5V

FREQUENCY COUNTER FC-510 (power supplay board)

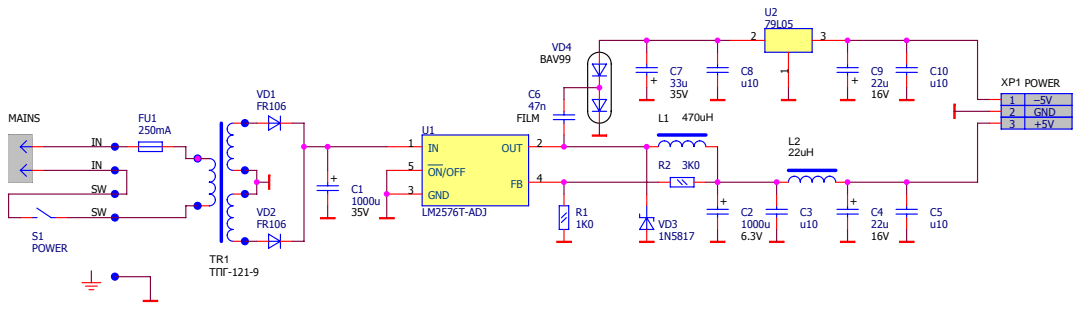
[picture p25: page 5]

1 | –5V
2 | GND
3 | +5V

FREQUENCY COUNTER FC-510 (power supplay board)

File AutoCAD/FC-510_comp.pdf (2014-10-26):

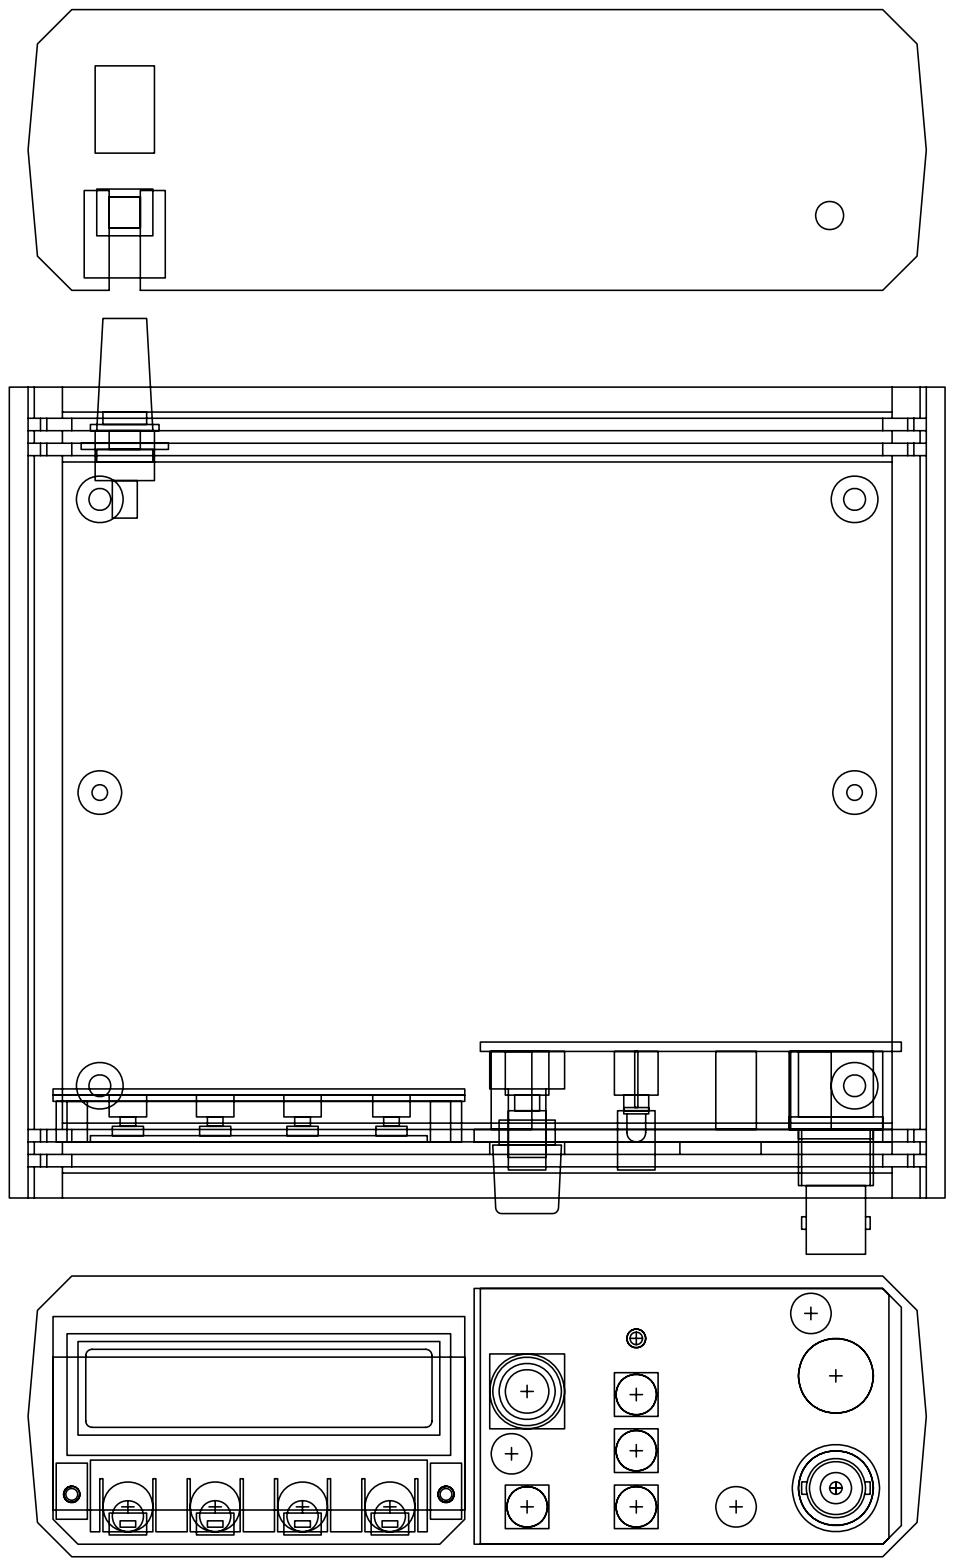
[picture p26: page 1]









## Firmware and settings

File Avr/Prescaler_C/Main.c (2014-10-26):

//----------------------------------------------------------------------------

//Project:         Prescaler (LMX2324)
//Version:         V1.0
//Compiler:        IAR EWAVR 5.30
//Microcontroller: ATtiny25
//E-mail:          wubblick@yahoo.com

//----------------------------------------------------------------------------

//Fuses: 0xD920
//SPI Enable          (SPIEN = 0)
//External clock      (SKSEL3 = 0, SKSEL2 = 0, SKSEL1 = 0, SKSEL0 = 0)  
//Startup 6CK + 65 ms (SUT0 = 0)
//BOD enabled, 4.0V   (BODLEVEL = 0, BODEN = 0)

//----------------------------------------------------------------------------

#include <iotiny25.h>
#include <intrinsics.h>

//----------------------------------------------------------------------------

#define N      256  //желаемый коэффициент деления

//----------------------------------------------------------------------------

#define PRE     32  //коэффициент деления встроенного прескалера
#define NB  (N / PRE)
#define NA  (N - NB * PRE)
#if (NA > NB) || (NB < 3) || (NB > 1023)
#error"Недопустимый коэффициент деления!"
#endif

#define BITS    18  //разрядность регистров

//биты регистра R:

#define TEST     1  //режим тестирования
#define RS       0  //зарезервированный бит
#define PD_POL   1  //вывод счетчика N
#define CP_TRI   1  //в режиме тестирования всегда =1
#define R_CNTR   2  //значение счетчика R (2..1023)
#define R_ADDR   1  //адрес регистра R

//биты регистра N:

#define NB_CNTR  NA //значение счетчика NA (0..31, NA <= NB)
#define NA_CNTR  NB //значение счетчика NB (3..1023)
#define CNT_RST  0  //режим сброса счетчиков
#define PWDN     0  //режим power down
#define N_ADDR   0  //адрес регистра N

//------------------------------- Порты : ------------------------------------

#define SDATA  (1 << PB0)
#define LE     (1 << PB1)
#define SCLK   (1 << PB2)
#define NC     (1 << PB3)
#define LED    (1 << PB4)

//Направление:
#define I_DDRB  (SDATA | LE | SCLK | LED)
//Начальное стостояние/pull-ups:
#define I_PORTB (SDATA | LE | SCLK | NC | LED)
//Макросы:
#define Port_SDATA_0 (PORTB &= ~SDATA)
#define Port_SDATA_1 (PORTB |= SDATA)
#define Port_LE_0    (PORTB &= ~LE)
#define Port_LE_1    (PORTB |= LE)
#define Port_SCLK_0  (PORTB &= ~SCLK)
#define Port_SCLK_1  (PORTB |= SCLK)
#define Port_LED_0   (PORTB &= ~SCLOCK)
#define Port_LED_1   (PORTB |= SCLOCK)

//-------------------------- Прототипы функций: ------------------------------

void main(void);
void SPI_Load(long n);

//------------------------- Основная программа: ------------------------------

void main(void)
{
  DDRB  = I_DDRB;
  PORTB = I_PORTB;
  //загрузка регистра N:
  SPI_Load((NB_CNTR <<  8) |
           (NA_CNTR <<  3) |
           (CNT_RST <<  2) |
              (PWDN <<  1) |
            (N_ADDR <<  0));
  //загрузка регистра R:
  SPI_Load(   (TEST << 14) |
                (RS << 13) |
            (PD_POL << 12) |
            (CP_TRI << 11) |
            (R_CNTR <<  1) |
            (R_ADDR <<  0));
  __sleep();
}

//------------------ Функция загрузка BITS битов по SPI: ---------------------

void SPI_Load(long n)
{
  Port_LE_0;
  for(char i = 0; i < BITS; i++)
  {
    Port_SCLK_0;
    if(n & (1L << (BITS - 1)))
      Port_SDATA_1;
        else Port_SDATA_0;
    n = n << 1;    
    Port_SCLK_1;
  }
  Port_SDATA_1;
  Port_LE_1;
}

//----------------------------------------------------------------------------

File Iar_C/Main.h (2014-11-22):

//----------------------------------------------------------------------------

//Frequency Counter FC-510
//main module header file

//----------------------------------------------------------------------------

#ifndef MainH
#define MainH

//----------------------------------------------------------------------------

#include <iom8.h>
#include <intrinsics.h>
#include <stdbool.h>
#include <stdlib.h>

//------------------------------- Constants: ---------------------------------

//#define       F_CLK    5.000 //clock frequency, MHz
//#define	F_CLK   10.000 //clock frequency, MHz
//#define	F_CLK   12.000 //clock frequency, MHz
//#define	F_CLK   12.288 //clock frequency, MHz
#define	F_CLK   12.800 //clock frequency, MHz
//#define	F_CLK   13.000 //clock frequency, MHz
//#define	F_CLK   14.400 //clock frequency, MHz
//#define       F_CLK   15.000 //clock frequency, MHz
//#define       F_CLK   16.000 //clock frequency, MHz
//#define	F_CLK   16.368 //clock frequency, MHz
//#define	F_CLK   16.369 //clock frequency, MHz
//#define	F_CLK   16.384 //clock frequency, MHz
//#define	F_CLK   17.500 //clock frequency, MHz

#define T_SYS    500.0 //system tick, uS

//----------------------------------------------------------------------------
//-------------------------------- Ports: ------------------------------------
//----------------------------------------------------------------------------

//Legend:

//I - input
//O - outbut
//B - bidirectional

//L - low active level
//H - high active level
//X - undefined active level
//A - analog signal

//------------------------------- Port B: ------------------------------------

#define SCLOCK (1 << PB0) //OX - CPLD serial clock
#define SDATA  (1 << PB1) //IX - CPLD serial data
#define RETL   (1 << PB2) //IL - keyboard return line
#define LOAD   (1 << PB3) //OL - LCD load strobe
#define DATA   (1 << PB4) //OX - LCD serial data
#define SCLK   (1 << PB5) //OX - LCD serial clock
#define NC_PB6 (1 << PB6) //IL - not used
#define NC_PB7 (1 << PB7) //IL - not used

//Direction:
#define I_DDRB  (SCLOCK | LOAD | DATA | SCLK)
//Pull-ups (in) or initial state (out):
#define I_PORTB (SDATA | RETL | LOAD | DATA | SCLK | NC_PB6 | NC_PB7)
//Port control macros:
#define Port_SCLOCK_0 (PORTB &= ~SCLOCK)
#define Port_SCLOCK_1 (PORTB |= SCLOCK)
#define Pin_SDATA     (PINB & SDATA)
#define Pin_RETL      (PINB & RETL)
#define Port_LOAD_0   (PORTB &= ~LOAD)
#define Port_LOAD_1   (PORTB |= LOAD)
#define Port_DATA_0   (PORTB &= ~DATA)
#define Port_DATA_1   (PORTB |= DATA)
#define Port_SCLK_0   (PORTB &= ~SCLK)
#define Port_SCLK_1   (PORTB |= SCLK)

//------------------------------- Port C: ------------------------------------

#define FDIV   (1 << PC0) //IH - frequency divider sense
#define LED    (1 << PC1) //OH - gate LED
#define SND    (1 << PC2) //OL - sound generation
#define FSYNC  (1 << PC3) //OL - CPLD frame synchronization
#define RESET  (1 << PC4) //OL - CPLD reset
#define CALIB  (1 << PC5) //OH - CPLD calibrate
#define NC_PC6 (1 << PC6) //IL - not used

//Direction:
#define I_DDRC  (LED | SND | FSYNC | RESET | CALIB)
//Pull-ups (in) or initial state (out):
#define I_PORTC (FDIV | SND | FSYNC | RESET | NC_PC6)
//Port control macros:
#define Pin_FDIV      (PINC & FDIV)
#define Port_LED_0    (PORTC &= ~LED)
#define Port_LED_1    (PORTC |= LED)
#define Port_SND_0    (PORTC &= ~SND)
#define Port_SND_1    (PORTC |= SND)
#define Port_SND      (PORTC & SND)
#define Port_FSYNC_0  (PORTC &= ~FSYNC)
#define Port_FSYNC_1  (PORTC |= FSYNC)
#define Port_RESET_0  (PORTC &= ~RESET)
#define Port_RESET_1  (PORTC |= RESET)
#define Port_CALIB_0  (PORTC &= ~CALIB)
#define Port_CALIB_1  (PORTC |= CALIB)

//------------------------------- Port D: ------------------------------------

#define RXD    (1 << PD0) //IL - serial port RXD
#define TXD    (1 << PD1) //OL - serial port TXD
#define GATE   (1 << PD2) //OH - CPLD gate
#define MODE2  (1 << PD3) //IL - CPLD mode 2
#define QFREF  (1 << PD4) //IX - TO counter input
#define QFIN   (1 << PD5) //IX - T1 counter input
#define MODE0  (1 << PD6) //IL - CPLD mode 0
#define MODE1  (1 << PD7) //IL - CPLD mode 1

//Direction:
#define I_DDRD  (TXD | GATE | MODE2 | MODE0 | MODE1)
//Pull-ups (in) or initial state (out):
#define I_PORTD (RXD | TXD | QFREF | QFIN)
//Port control macros:
#define Port_GATE_0   (PORTD &= ~GATE)
#define Port_GATE_1   (PORTD |= GATE)
#define Port_MODE2_0  (PORTD &= ~MODE2)
#define Port_MODE2_1  (PORTD |= MODE2)
#define Port_MODE0_0  (PORTD &= ~MODE0)
#define Port_MODE0_1  (PORTD |= MODE0)
#define Port_MODE1_0  (PORTD &= ~MODE1)
#define Port_MODE1_1  (PORTD |= MODE1)

//------------------------------- Macros: ------------------------------------

#define HI(x) ((x >> 8) & 0xFF)
#define LO(x) (x & 0xFF)
#define Delay_us(x) __delay_cycles((int)(x * F_CLK + 0.5))
#define ms2sys(x) ((int)(1E3 * x / T_SYS))
#define ABS(x) ((x < 0)? (-x) : (x))

//----------------------------------------------------------------------------

#endif

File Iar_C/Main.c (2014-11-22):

//----------------------------------------------------------------------------

//Project:         Frequency Counter FC-510
//Version:         V1.7
//Compiler:        IAR EWAVR 6.21
//Microcontroller: ATmega8
//E-mail:          wubblick@yahoo.com

//----------------------------------------------------------------------------

//Fuses: 0xD920
//SPI Enable          (SPIEN = 0)
//External clock      (SKSEL3 = 0, SKSEL2 = 0, SKSEL1 = 0, SKSEL0 = 0)
//Startup 6CK + 65 ms (SUT0 = 0)
//BOD enabled, 4.0V   (BODLEVEL = 0, BODEN = 0)

//----------------------------------------------------------------------------

#include "Main.h"
#include "Count.h"
#include "Menu.h"
#include "Sound.h"

//------------------------------ Variables: ----------------------------------

volatile bool fTick; //system timer update flag
static bool tick;    //system tick

//------------------------- Function prototypes: -----------------------------

void main(void);                  //main program
void Main_Wdt_Init(void);         //watchdog timer init
void Main_Rst_Wdt(bool t);        //watchdog timer restart
void Main_Ports_Init(void);       //ports init
void Main_Timer_Init(void);       //system timer init
bool Main_GetTick(void);          //get new tick
#pragma vector = TIMER2_COMP_vect
__interrupt void Timer(void);     //system timer interrupt

//----------------------------------------------------------------------------
//---------------------------- Main program: ---------------------------------
//----------------------------------------------------------------------------

void main(void)
{
  Main_Wdt_Init();           //watchdog timer init
  Main_Ports_Init();         //ports init
  Main_Timer_Init();         //system timer init
  Count_Init();              //counter init
  Menu_Init();               //menu init
  __enable_interrupt();      //interrupts enable

  while(1)                   //main cycle
  {
    tick = Main_GetTick();   //tick update check
    Count_Exe(tick);         //do count
    Menu_Exe(tick);          //process menu
    Main_Rst_Wdt(tick);      //watchdog timer restart
  }
}

//----------------------------------------------------------------------------
//----------------------------------------------------------------------------
//----------------------------------------------------------------------------

//------------------------- Watchdog timer init: -----------------------------

void Main_Wdt_Init(void)
{
  __watchdog_reset();
  WDTCR = (1 << WDCE) | (1 << WDE);
  WDTCR = (1 << WDE) | (1 << WDP2) | (1 << WDP1); //1 s
}

//------------------------ Watchdog timer restart: ---------------------------

void Main_Rst_Wdt(bool t)
{
  if(t)                 //if new tick,
    __watchdog_reset(); //restart watchdog timer
}

//----------------------------- Ports init: ----------------------------------

void Main_Ports_Init(void)
{
  DDRB  = I_DDRB;
  PORTB = I_PORTB;
  DDRC  = I_DDRC;
  PORTC = I_PORTC;
  DDRD  = I_DDRD;
  PORTD = I_PORTD;
}

//------------------------- System timer init: -------------------------------

void Main_Timer_Init(void)
{
  TCCR2 = (1 << WGM21) | (1 << CS22); //timer 2 mode: CTC, CK/64
  OCR2 = (char)(F_CLK * T_SYS / 64.0 - 0.5); //load compare register
  TIFR = (1 << OCIE2);                //pending interrupts clear
  TIMSK |= (1 << OCIE2);              //compare interrupt enable
  fTick = 1;                          //force update
}

//------------------------- System timer check: ------------------------------

__monitor bool Main_GetTick(void)
{
  if(!fTick) return(0); //check system timer update
  fTick = 0; return(1); //new system tick, clear update flag
}

//------------------------ System timer interrupt: ---------------------------

#pragma vector = TIMER2_COMP_vect
__interrupt void Timer(void)
{
  fTick = 1;   //clear timer update flag
  Sound_Gen(); //sound generation
}

//----------------------------------------------------------------------------
